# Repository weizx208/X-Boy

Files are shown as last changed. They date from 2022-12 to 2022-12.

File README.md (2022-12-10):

**基于全志V3s自制GBA开源游戏掌机**

视频介绍 [https://www.bilibili.com/video/BV1JP4y1X7Uz](https://www.bilibili.com/video/BV1JP4y1X7Uz/?vd_source=2f25de86752ccc9cfafc4bcf1c352db1)

图片展示

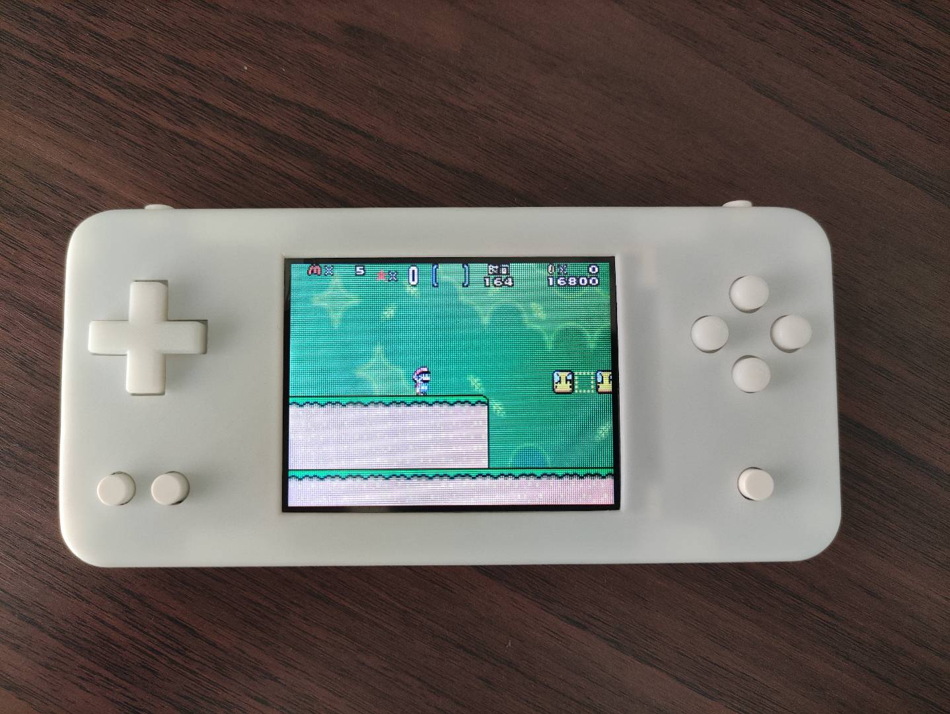
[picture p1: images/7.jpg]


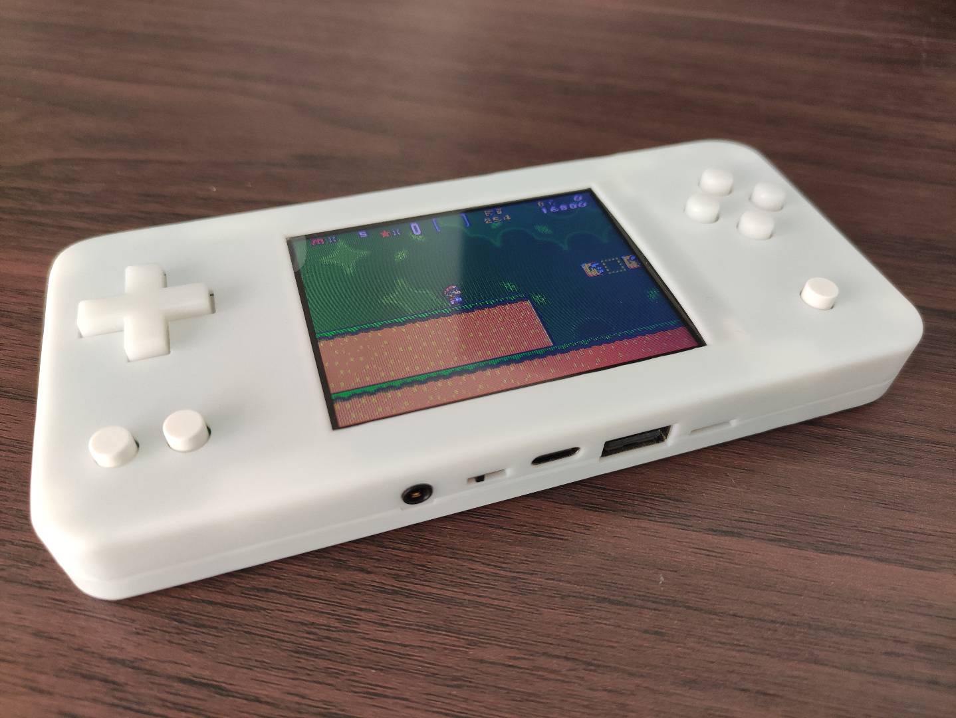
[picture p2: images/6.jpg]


以下内容为镜像的构建过程，你也可以直接使用我制作好的镜像

> 百度网盘
> 
> 链接：https://pan.baidu.com/s/1ftacGCXHLy-AFabczBg3yg
>
> 提取码：9bp8

**X-Boy 系统镜像构建全流程指南**

- [ubuntu 系统安装](#ubuntu-系统安装)
	- [下载镜像](#下载镜像)
	- [换源](#换源)
		- [备份源列表](#备份源列表)
		- [修改 sources.list 文件](#修改-sourceslist-文件)
		- [更改为清华镜像源](#更改为清华镜像源)
		- [更新并升级](#更新并升级)
		- [安装依赖库](#安装依赖库)
- [安装交叉编译工具链](#安装交叉编译工具链)
	- [安装编译器](#安装编译器)
		- [新建 tool 文件夹并进入](#新建-tool-文件夹并进入)
		- [下载交叉编译链](#下载交叉编译链)
		- [创建文件夹并解压](#创建文件夹并解压)
		- [配置环境变量](#配置环境变量)
		- [安装其他库](#安装其他库)
		- [验证是否安装成功](#验证是否安装成功)
- [uboot 编译](#uboot-编译)
	- [获取 uboot](#获取-uboot)
	- [修改 include/configs/sun8i.h](#修改-includeconfigssun8ih)
	- [编译 uboot](#编译-uboot)
- [主线 Linux 编译](#主线-linux-编译)
	- [下载源码](#下载源码)
	- [修改顶层 Makefile](#修改顶层-makefile)
	- [配置 ili9341 LCD](#配置-ili9341-lcd)
	- [编译](#编译)
- [Buildroot 根文件系统构建](#buildroot-根文件系统构建)
	- [获取 Buildroot](#获取-buildroot)
	- [基本配置](#基本配置)
	- [编译链工具配置](#编译链工具配置)
	- [alsa、sdl、fbv配置](#alsasdlfbv配置)
	- [编译](#编译-1)
- [TF 卡分区及烧录](#tf-卡分区及烧录)
	- [TF 卡分区](#tf-卡分区)
	- [烧录 uboot](#烧录-uboot)
	- [写入内核和设备树](#写入内核和设备树)
	- [写入根文件系统](#写入根文件系统)
- [编译模拟器](#编译模拟器)
	- [编译 gpsp](#编译-gpsp)
	- [复制可执行文件](#复制可执行文件)
- [系统配置](#系统配置)
	- [自动挂载 fat 分区](#自动挂载-fat-分区)
	- [配置双端显示](#配置双端显示)
	- [启动后开启声音](#启动后开启声音)
	- [配置 SDL 环境](#配置-sdl-环境)
	- [自启动模拟器](#自启动模拟器)
- [制作镜像](#制作镜像)
	- [创建工作目录](#创建工作目录)
	- [创建空白文件并分区](#创建空白文件并分区)
	- [将镜像文件虚拟成块设备](#将镜像文件虚拟成块设备)
	- [格式化块设备并且挂载](#格式化块设备并且挂载)
	- [烧录 uboot](#烧录-uboot-1)
	- [写入内核和设备树](#写入内核和设备树-1)
	- [写入根文件系统](#写入根文件系统-1)
- [感谢](#感谢)
- [参考链接](#参考链接)

---

## ubuntu 系统安装

### 下载镜像

```
https://mirrors.tuna.tsinghua.edu.cn/ubuntu-releases/18.04/ubuntu-18.04.6-desktop-amd64.iso
```

使用物理机或者虚拟机安装都可以

### 换源

#### 备份源列表

```
sudo cp /etc/apt/sources.list /etc/apt/sources.list.bak
```
#### 修改 sources.list 文件

```
sudo gedit /etc/apt/sources.list
```

#### 更改为清华镜像源

```
# 默认注释了源码镜像以提高 apt update 速度，如有需要可自行取消注释
deb https://mirrors.tuna.tsinghua.edu.cn/ubuntu/ bionic main restricted universe multiverse
# deb-src https://mirrors.tuna.tsinghua.edu.cn/ubuntu/ bionic main restricted universe multiverse
deb https://mirrors.tuna.tsinghua.edu.cn/ubuntu/ bionic-updates main restricted universe multiverse
# deb-src https://mirrors.tuna.tsinghua.edu.cn/ubuntu/ bionic-updates main restricted universe multiverse
deb https://mirrors.tuna.tsinghua.edu.cn/ubuntu/ bionic-backports main restricted universe multiverse
# deb-src https://mirrors.tuna.tsinghua.edu.cn/ubuntu/ bionic-backports main restricted universe multiverse
deb https://mirrors.tuna.tsinghua.edu.cn/ubuntu/ bionic-security main restricted universe multiverse
# deb-src https://mirrors.tuna.tsinghua.edu.cn/ubuntu/ bionic-security main restricted universe multiverse
# 预发布软件源，不建议启用
# deb https://mirrors.tuna.tsinghua.edu.cn/ubuntu/ bionic-proposed main restricted universe multiverse
# deb-src https://mirrors.tuna.tsinghua.edu.cn/ubuntu/ bionic-proposed main restricted universe multiverse
```

#### 更新并升级

```
sudo apt-get update && sudo apt-get upgrade
```

#### 安装依赖库

```
sudo apt-get install -y device-tree-compiler python flex bison ncurses-dev libssl-dev
```

## 安装交叉编译工具链

### 安装编译器

#### 新建 tool 文件夹并进入

```
mkdir ~/linux/tools && cd ~/linux/tools
```

#### 下载交叉编译链

```
wget https://releases.linaro.org/components/toolchain/binaries/4.9-2017.01/arm-linux-gnueabihf/gcc-linaro-4.9.4-2017.01-x86_64_arm-linux-gnueabihf.tar.xz
```

#### 创建文件夹并解压

```
sudo mkdir /usr/local/arm && sudo tar -vxf gcc-linaro-4.9.4-2017.01-x86_64_arm-linux-gnueabihf.tar.xz -C /usr/local/arm
```

#### 配置环境变量

```
sudo vim ~/.bashrc
export PATH=$PATH:/usr/local/arm/gcc-linaro-4.9.4-2017.01-x86_64_arm-linux-gnueabihf/bin
source ~/.bashrc
```
#### 安装其他库

```
sudo apt-get install lsb-core lib32stdc++6
```

#### 验证是否安装成功

```
arm-linux-gnueabihf-gcc -v
```

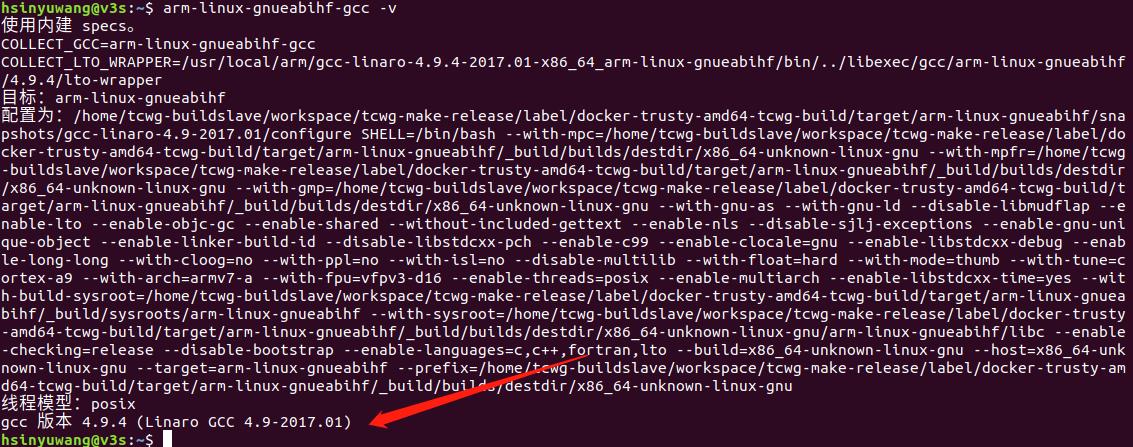
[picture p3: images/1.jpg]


## uboot 编译

### 获取 uboot

```
mkdir ~/v3s && cd ~/v3s
git clone https://github.com/Lichee-Pi/u-boot.git -b v3s-current
```
uboot 的目录结构

```
├── api                存放uboot提供的API接口函数
├── arch               平台相关的部分我们只需要关心这个目录下的ARM文件夹
│   ├──arm
│   │   └──cpu
│   │   │   └──armv7
│   │   └──dts
│   │   │   └──*.dts 存放设备的dts,也就是设备配置相关的引脚信息
├── board              对于不同的平台的开发板对应的代码
├── cmd                顾名思义，大部分的命令的实现都在这个文件夹下面。
├── common             公共的代码
├── configs            各个板子的对应的配置文件都在里面，我们的Lichee配置也在里面
├── disk               对磁盘的一些操作都在这个文件夹里面，例如分区等。
├── doc                参考文档，这里面有很多跟平台等相关的使用文档。
├── drivers            各式各样的驱动文件都在这里面
├── dts                一种树形结构（device tree）这个应该是uboot新的语法
├── examples           官方给出的一些样例程序
├── fs                 文件系统，uboot会用到的一些文件系统
├── include            头文件，所有的头文件都在这个文件夹下面
├── lib                一些常用的库文件在这个文件夹下面
├── Licenses           这个其实跟编译无关了，就是一些license的声明
├── net                网络相关的，需要用的小型网络协议栈
├── post              上电自检程序
├── scripts           编译脚本和Makefile文件
├── spl               second program loader，即相当于二级uboot启动。
├── test              小型的单元测试程序。
└── tools             里面有很多uboot常用的工具。
```
### 修改 include/configs/sun8i.h

在文件中添加

```
#define CONFIG_BOOTCOMMAND  "setenv bootm_boot_mode sec; " \
                            "load mmc 0:1 0x41000000 zImage; "  \
                            "load mmc 0:1 0x41800000 sun8i-v3s-licheepi-zero-dock.dtb; " \
                            "bootz 0x41000000 - 0x41800000;"

#define CONFIG_BOOTARGS "console=tty0 console=ttyS0,115200 panic=5 rootwait root=/dev/mmcblk0p2 earlyprintk rw  vt.global_cursor_default=0"
```

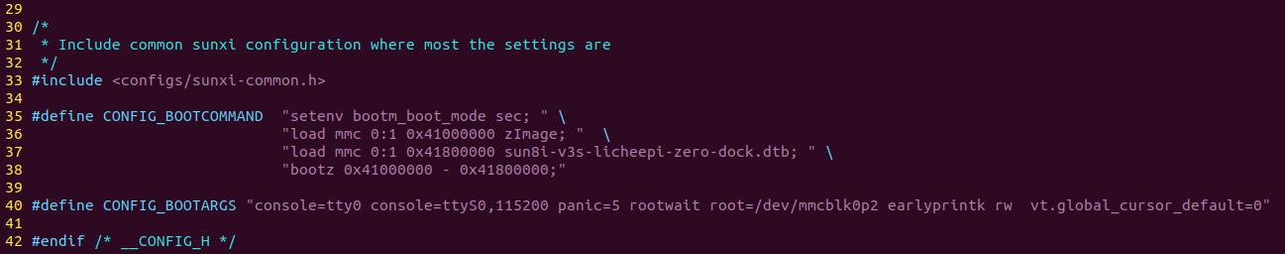
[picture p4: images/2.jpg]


### 编译 uboot

```
cd u-boot
make ARCH=arm CROSS_COMPILE=arm-linux-gnueabihf- LicheePi_Zero_defconfig
make ARCH=arm menuconfig
time make ARCH=arm CROSS_COMPILE=arm-linux-gnueabihf- 2>&1 | tee build.log
```

在 uboot 顶层 Makefile 的 248 行，添加默认编译器，就可以直接用 make 编译了。

```
# set default to nothing for native builds
ifeq ($(HOSTARCH),$(ARCH))
CROSS_COMPILE ?= 
endif

ARCH  ?= arm
CROSS_COMPILE ?= arm-linux-gnueabihf-

KCONFIG_CONFIG	?= .config
export KCONFIG_CONFIG
```

编译成功

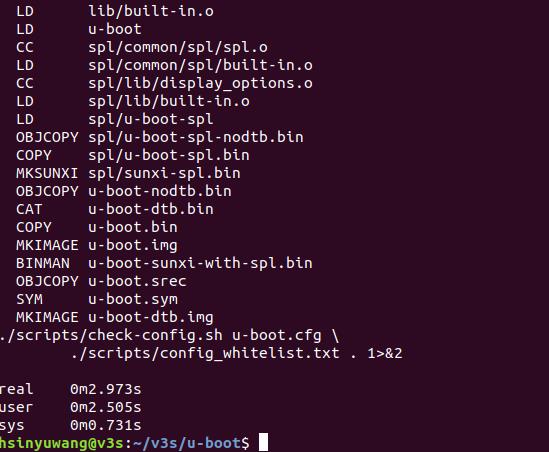
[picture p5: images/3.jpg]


后面编译好 kernel 和 rootfs 然后一起烧录

## 主线 Linux 编译

### 下载源码

```
cd ~/v3s
git clone -b zero-5.2.y https://github.com/Lichee-Pi/linux.git
```

### 修改顶层 Makefile

在内核根目录下的 Makefile 364 行修改默认编译器，可以直接用 make 编译

```
# ARCH		?= $(SUBARCH)
ARCH		?= arm
CROSS_COMPILE	?= arm-linux-gnueabihf-
```

### 配置 ili9341 LCD

```
cd linux
make licheepi_zero_defconfig
make menuconfig
```

勾选驱动

```
Device Drivers  --->
    Input device support  --->
        <*>   Joystick interface
        [*]   Joysticks/Gamepads  --->
             <*>   X-Box gamepad support
             [*]   X-Box gamepad rumble support
             [*]   LED Support for Xbox360 controller 'BigX' LED
    [ * ] Staging drivers  --->
        <*>   Support for small TFT LCD display modules  --->
                <*>   FB driver for the ILI9341 LCD Controller
                <*>   Generic FB driver for TFT LCD displays
```

修改设备树 arch/arm/boot/dts/sun8i-v3s-licheepi-zero.dts

在 chosen 中添加 /delete-node/ framebuffer@0; 删除原来的 simplefb 节点（ uboot 里有使能 fb 的操作，必须删除而不是 disable ）

```
chosen {
		stdout-path = "serial0:115200n8";
		/delete-node/ framebuffer@0;
	};
```

删除 &i2c0 节点

```
&i2c0 {
	status = "okay";

	ns2009: ns2009@48 {
		compatible = "nsiway,ns2009";
		reg = <0x48>;
	};
};
```

修改设备树 arch/arm/boot/dts/sun8i-v3s-licheepi-zero-dock.dts

删除 &lradc 和 &i2c0 （ lradc 用不到，gt911 占用引脚和屏幕的 spi 引脚有冲突，所以删掉）

```
&lradc {
	vref-supply = <&reg_vcc3v0>;
	status = "okay";

	button-200 {
		label = "Volume Up";
		linux,code = <KEY_VOLUMEUP>;
		channel = <0>;
		voltage = <200000>;
	};

	button-400 {
		label = "Volume Down";
		linux,code = <KEY_VOLUMEDOWN>;
		channel = <0>;
		voltage = <400000>;
	};

	button-600 {
		label = "Select";
		linux,code = <KEY_SELECT>;
		channel = <0>;
		voltage = <600000>;
	};

	button-800 {
		label = "Start";
		linux,code = <KEY_OK>;
		channel = <0>;
		voltage = <800000>;
	};
};

&i2c0 {
	gt911: touchscreen@14 {
        compatible = "goodix,gt911";
        reg = <0x5d>;
        interrupt-parent = <&pio>;
        interrupts = <1 5 IRQ_TYPE_EDGE_FALLING>; /* (PB5) */
        pinctrl-names = "default";
        irq-gpios = <&pio 1 5 GPIO_ACTIVE_HIGH>; /* (PB5) */
        reset-gpios = <&pio 2 1 GPIO_ACTIVE_HIGH>; /* RST (PC1) */
        /* touchscreen-swapped-x-y */
    };
};
```

在最后添加

```
&spi0 {
       status = "okay";

       ili9341@0 {
               compatible = "ilitek,ili9341";
               reg = <0>;

               spi-max-frequency = <60000000>;
               rotate = <270>;
               bgr;
               fps = <50>;
               buswidth = <8>;
               reset-gpios = <&pio 1 2 GPIO_ACTIVE_LOW>;
               dc-gpios = <&pio 1 5 GPIO_ACTIVE_LOW>;
               debug = <0>;
       };
};
```

这样启动时的信息会通过 ili9341 LCD 显示

5.2 内核需要修改 drivers/staging/fbtft/fbtft_core.c 的 fbtft_request_one_gpio() 方法，否则开机 log 会报申请 gpio 失败

注意需要在该文件引入下面头文件，否则编译报错

```
#include <linux/of_gpio.h>
```

```
static int fbtft_request_one_gpio(struct fbtft_par *par,
                  const char *name, int index,
                  struct gpio_desc **gpiop)
{
    struct device *dev = par->info->device;
    struct device_node *node = dev->of_node;
    int gpio, flags, ret = 0;
    enum of_gpio_flags of_flags;
    if (of_find_property(node, name, NULL)) {
        gpio = of_get_named_gpio_flags(node, name, index, &of_flags);
        if (gpio == -ENOENT)
            return 0;
        if (gpio == -EPROBE_DEFER)
            return gpio;
        if (gpio < 0) {
            dev_err(dev,
                "failed to get '%s' from DT\n", name);
            return gpio;
        }
         //active low translates to initially low
        flags = (of_flags & OF_GPIO_ACTIVE_LOW) ? GPIOF_OUT_INIT_LOW :
                            GPIOF_OUT_INIT_HIGH;
        ret = devm_gpio_request_one(dev, gpio, flags,
                        dev->driver->name);
        if (ret) {
            dev_err(dev,
                "gpio_request_one('%s'=%d) failed with %d\n",
                name, gpio, ret);
            return ret;
        }
 
        *gpiop = gpio_to_desc(gpio);
        fbtft_par_dbg(DEBUG_REQUEST_GPIOS, par, "%s: '%s' = GPIO%d\n",
                            __func__, name, gpio);
    }
 
    return ret;
}
```

修改引脚 bug

fbtft_bus.c 的 fbtft_write_vmem16_bus8() 方法

```
int fbtft_write_vmem16_bus8(struct fbtft_par *par, size_t offset, size_t len)
{
	u16 *vmem16;
	__be16 *txbuf16 = par->txbuf.buf;
	size_t remain;
	size_t to_copy;
	size_t tx_array_size;
	int i;
	int ret = 0;
	size_t startbyte_size = 0;
 
	fbtft_par_dbg(DEBUG_WRITE_VMEM, par, "%s(offset=%zu, len=%zu)\n",
		      __func__, offset, len);
 
	remain = len / 2;
	vmem16 = (u16 *)(par->info->screen_buffer + offset);
 
	if (par->gpio.dc)
	{
		//printk("dc拉高！\n");
		gpiod_set_value(par->gpio.dc, 1);
	}
	/* non buffered write */
	if (!par->txbuf.buf)
		return par->fbtftops.write(par, vmem16, len);
 
	/* buffered write */
	tx_array_size = par->txbuf.len / 2;
 
	if (par->startbyte) {
		txbuf16 = par->txbuf.buf + 1;
		tx_array_size -= 2;
		*(u8 *)(par->txbuf.buf) = par->startbyte | 0x2;
		startbyte_size = 1;
	}
 
	while (remain) {
		to_copy = min(tx_array_size, remain);
		dev_dbg(par->info->device, "to_copy=%zu, remain=%zu\n",
			to_copy, remain - to_copy);
 
		for (i = 0; i < to_copy; i++)
			txbuf16[i] = cpu_to_be16(vmem16[i]);
 
		vmem16 = vmem16 + to_copy;
		ret = par->fbtftops.write(par, par->txbuf.buf,
						startbyte_size + to_copy * 2);
		if (ret < 0)
			return ret;
		remain -= to_copy;
	}
 
	return ret;
}
```

### 编译

```
make -j4
make -j4 INSTALL_MOD_PATH=out modules
make -j4 INSTALL_MOD_PATH=out modules_install
# 修改了设备树文件后编译
make dtbs
```

- 编译完成后，zImage 在 arch/arm/boot/ ，驱动模块在 out/
- 设备树文件在 arch/arm/boot/dts/
- dock板的设备树：sun8i-v3s-licheepi-zero-dock.dtb

## Buildroot 根文件系统构建

### 获取 Buildroot

```
cd ~/v3s
wget https://buildroot.org/downloads/buildroot-2019.08.tar.gz
tar xvf buildroot-2019.08.tar.gz && cd buildroot-2019.08/
make menuconfig
```

### 基本配置

```
Target options  --->
	Target Architecture (ARM (little endian))  --->
	Target Binary Format (ELF)  --->
	Target Architecture Variant (cortex-A7)  --->
	Target ABI (EABIhf)  --->
	Floating point strategy (VFPv4-D16)  --->
	ARM instruction set (ARM)  ---> 
```

### 编译链工具配置

```
Toolchain  --->
	Toolchain type (External toolchain)  --->
	*** Toolchain External Options ***
	Toolchain (Custom toolchain)  --->
	Toolchain origin (Pre-installed toolchain)  --->
	(/usr/local/arm/gcc-linaro-4.9.4-2017.01-x86_64_arm-linux-gnueabihf/) Toolchain path
	($(ARCH)-linux-gnueabihf) Toolchain prefix
	External toolchain gcc version (4.9.x)  --->
	External toolchain kernel headers series (4.0.x)  --->
	External toolchain C library (glibc/eglibc)  --->
	[*] Toolchain has SSP support? (NEW)
	[*] Toolchain has RPC support? (NEW)
	[*] Toolchain has C++ support? 
	[*] Enable MMU support (NEW) 
```

### alsa、sdl、fbv配置

```
Target packages  --->
	Audio and video applications  --->
		[*] alsa-utils  --->
		[*]   alsaconf
		[*]   aconnect
		[*]   alsactl
		[*]   alsaloop
		[*]   alsamixer
		[*]   alsaucm
		[*]   alsatplg
		[*]   amidi
		[*]   amixer
		[*]   aplay/arecord
		[*]   aplaymidi
		[*]   arecordmidi
		[*]   aseqdump
		[*]   aseqnet
		[*]   bat
		[*]   iecset
		[*]   speaker-test
	Graphic libraries and applications (graphic/text)  --->
		[*] fbv
		[*]   PNG support
		[*]   JPEG support
		[*]   GIF support 
		[*] SDL
		[*]   SDL framebuffer console video driver
		[*]   SDL_gfx
		[*]   SDL_image  --->
		[*]   SDL_mixer
		[*]   SDL_net
		[*]   SDL_sound
		[*]     install playsound tool
		[*]   SDL_TTF
```
### 编译

```
make -j4
```

生成的根文件系统在 output/images/rootfs.tar

## TF 卡分区及烧录

### TF 卡分区

```
sudo fdisk -l     		# 首先查看电脑上已插入的TF卡的设备号（一般为 /dev/sdb1,下面以/dev/sdb1为例）
sudo umount /dev/sdb1 	# 若自动挂载了TF设备，请先卸载(有多个分区则全部卸载)
sudo umount /dev/sdb2
sudo fdisk /dev/sdb   	# 进行分区操作
##### 操作步骤如下 #####
# 若已存分区即按 d 删除各个分区
# 通过 n 新建分区，第一分区暂且申请为16M(f1c100s)、32M(v3s)，剩下的空间都给第二分区
	# 第一分区操作：n p 1 2048 +32M
		# p 主分区、默认 1 分区、默认2048、+32M
	# 第二分区操作：n 后面全部回车默认即可
		# p 主分区、默认 2 分区、默认、默认剩下的全部空间
# p 查询分区表确定是否分区成功
# w 保存写入并退出
########################

sudo mkfs.ext4 /dev/sdb1 # 将第一分区格式化成EXT4
sudo mkfs.ext4 /dev/sdb2 # 将第二分区格式化成EXT4

# 格式说明
	# EXT4：只用于Linux系统的内部磁盘
	# NTFS：与Windows共用的磁盘
	# FAT：所有系统和设备共用的磁盘
```

后期为了能够在 windows 上方便添加 rom ，使用 gparted 划分三个分区，最后一个分区为 fat 类型

安装并启动

```
sudo apt-get install gparted
sudo gparted
```

分区如下

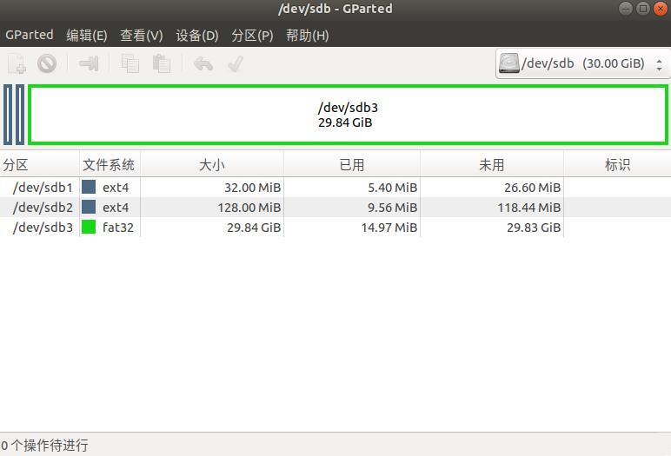
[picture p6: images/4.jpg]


### 烧录 uboot

```
cd ~/v3s/u-boot/
sudo dd if=u-boot-sunxi-with-spl.bin of=/dev/sdb bs=1024 seek=8
```
### 写入内核和设备树

```
sudo cp ~/v3s/linux/arch/arm/boot/zImage /挂载的tf卡第一个分区目录
sudo cp ~/v3s/linux/arch/arm/boot/dts/sun8i-v3s-licheepi-zero-dock.dtb /挂载 tf 卡第一个分区目录
```

### 写入根文件系统

```
sudo tar xvf ~/v3s/buildroot-2019.08/output/images/rootfs.tar -C /挂载 tf 卡第二个分区目录
```

## 编译模拟器

### 编译 gpsp

```
cd ~/v3s
git clone https://github.com/hsinyuwang/gpsp.git

cd gpsp/v3s
make -j4
```
### 复制可执行文件

将生成的可执行文件复制到挂载的 tf 卡第二个分区目录，gpsp 同级目录下必须包含 gba_bios.bin 和 game_config.txt 文件

例如：
- 在 /root 下创建 gpsp 文件夹，将 gpsp、gba_bios.bin、game_config.txt 复制到 gpsp 文件夹中
- 在 /root 下创建 fceux 文件夹，将 fceux 复制到 fceux 文件夹中

## 系统配置

插入 TF 卡，开机

### 自动挂载 fat 分区

```
mkdir /root/roms
vi /etc/fstab

# 最后一行添加
/dev/mmcblk0p3  /root/roms      vfat    defaults        0       0
```

### 配置双端显示

```
vi /etc/inittab

#console::respawn:-/bin/sh
ttyS0::respawn:-/bin/sh
tty0::respawn:-/bin/sh
```

### 启动后开启声音

```
vi /etc/init.d/S99runOnBoot

# 添加
amixer -c 0 sset 'Headphone',0 60% unmute

# 添加可执行权限
chmod +x /etc/init.d/S99runOnBoot
```

### 配置 SDL 环境

```
vi /etc/profile

# SDL 配置
export SDL_NOMOUSE=1

# 启动模拟器
/root/startup.sh
```

### 自启动模拟器

```
vi /root/startup.sh

#!/bin/sh /root/startup.sh
for i in `seq 5`
do
        sleep 1s
        if [ -c "/dev/input/js0" ]
        then
                /root/gpsp/gpsp
                break
        else
                if [ $i -eq 5 ]
                then
                        echo "No gamepad found!"
                fi
        fi
done

chmod +x startup.sh
```

## 制作镜像

### 创建工作目录

```
mkdir ~/img
cd ~/img
mkdir kernel
mkdir rootfs
mkdir roms
```

### 创建空白文件并分区

分区表

| 分区序号 | 起始地址 | 大小 | 内容 | 文件系统 |
| ---- | ---- | ---- | ---- | ---- |
| 1 | 0 | 1M | u-boot-sunxi-with-spl.bin | 无 |
| 2 | 1 x 1024 x 1024 | 32M | zImage + sun8i-v3s-licheepi-zero-dock.dtb | ext4 |
| 3 | 33 x 1024 x 1024 | 128M | rootfs | ext4 |
| 4 | 161 x 1024 x 1024 | 剩余空间 | roms | fat |

```
dd if=/dev/zero of=X-Boy_20221019.img bs=512k count=512  && sync
sudo parted X-Boy_20221019.img mklabel msdos
sudo parted X-Boy_20221019.img mkpart primary ext4 2048s 67583s
sudo parted X-Boy_20221019.img mkpart primary ext4 67584s 329727s
sudo parted X-Boy_20221019.img mkpart primary fat32 329728s 100%
```

检查分区是否创建成功

```
sudo parted X-Boy_20221019.img
```

输入

```
print free

# 退出
q
```

### 将镜像文件虚拟成块设备

```
sudo losetup -f --show X-Boy_20221019.img
```

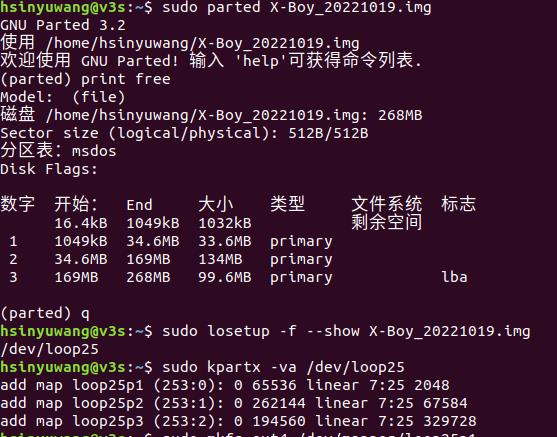
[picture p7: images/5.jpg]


这里的 loop25 记录下来 ，以实际显示为准

挂载虚拟文件系统

```
sudo kpartx -va /dev/loop25
```

### 格式化块设备并且挂载

格式化分区

```
sudo mkfs.ext4 /dev/mapper/loop25p1
sudo mkfs.ext4 /dev/mapper/loop25p2
sudo mkfs.vfat /dev/mapper/loop25p3
```

挂载到之前创建的目录

```
sudo mount /dev/mapper/loop25p1 ~/img/kernel/
sudo mount /dev/mapper/loop25p2 ~/img/rootfs/
sudo mount /dev/mapper/loop25p3 ~/img/roms/
```

### 烧录 uboot

```
cd ~/v3s/u-boot/
sudo dd if=u-boot-sunxi-with-spl.bin of=/dev/loop25 bs=512 seek=16
```

### 写入内核和设备树

```
sudo cp ~/v3s/linux/arch/arm/boot/zImage ~/img/kernel
sudo cp ~/v3s/linux/arch/arm/boot/dts/sun8i-v3s-licheepi-zero-dock.dtb ~/img/kernel
```

### 写入根文件系统

```
sudo tar xvf ~/v3s/buildroot-2019.08/output/images/rootfs.tar -C ~/img/rootfs
```

## 感谢

[steward-fu](https://github.com/steward-fu)

[STM32-X360-xinput](https://github.com/nesvera/STM32-X360-xinput)

## 参考链接

[全志V3S（荔枝派zero）学习笔记](https://blog.csdn.net/p1279030826/article/details/114981681)

[荔枝派Zero V3s开发板入坑记录](https://whycan.com/t_561.html)

[Linux系统中使用Xbox360手柄](http://t.zoukankan.com/beyonne-p-10932152.html)

[f1c100s spi fbtft ILI9341屏配置](https://blog.csdn.net/qulang000/article/details/114686525)

[点屏之SPI屏 ili9341](https://www.kancloud.cn/lichee/lpi0/538999)

[嵌入式Linux--荔枝派Zero--V3s--ST7789v](https://blog.csdn.net/qq_28877125/article/details/120007416)

[v3S驱动音频](https://blog.csdn.net/lengyuefeng212/article/details/120055703)

[制作imx6ull Linux系统的img镜像](https://blog.csdn.net/mzy2364/article/details/113364250)

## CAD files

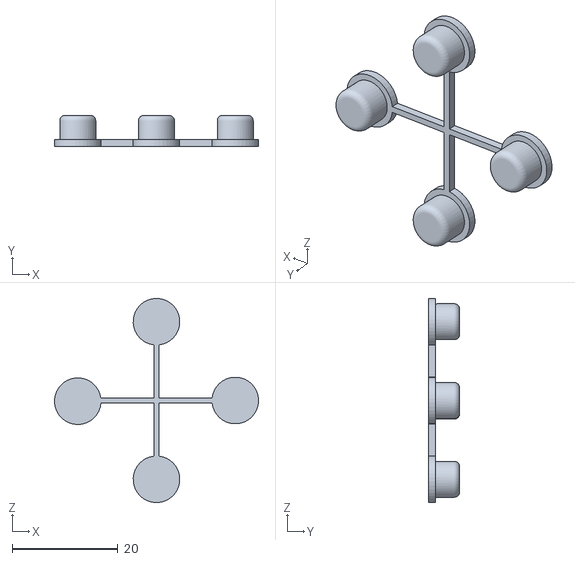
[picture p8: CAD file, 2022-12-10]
STL/ABXY.STL
38.5 x 5.90 x 38.5

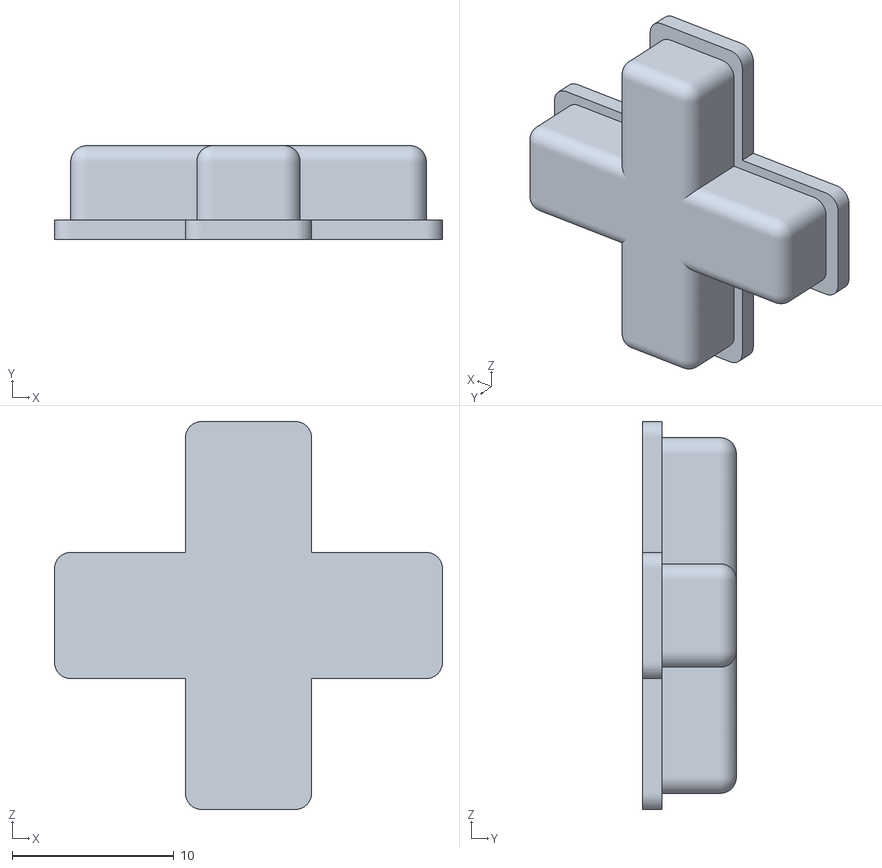
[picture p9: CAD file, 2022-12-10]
STL/十字键.STL
24.0 x 5.80 x 24.0

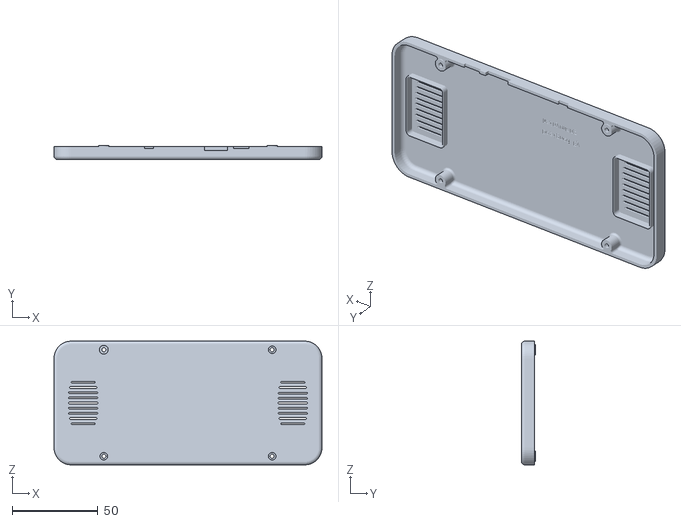
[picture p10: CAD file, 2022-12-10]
STL/下壳.STL
156.0 x 8.20 x 72.0

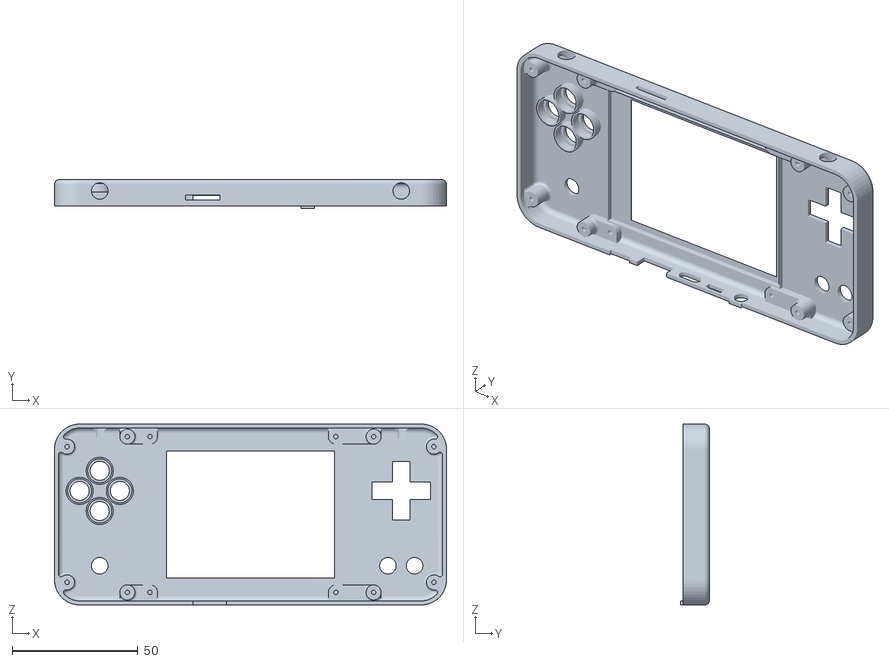
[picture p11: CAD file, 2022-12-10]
STL/上壳.STL
156.0 x 11.6 x 72.0

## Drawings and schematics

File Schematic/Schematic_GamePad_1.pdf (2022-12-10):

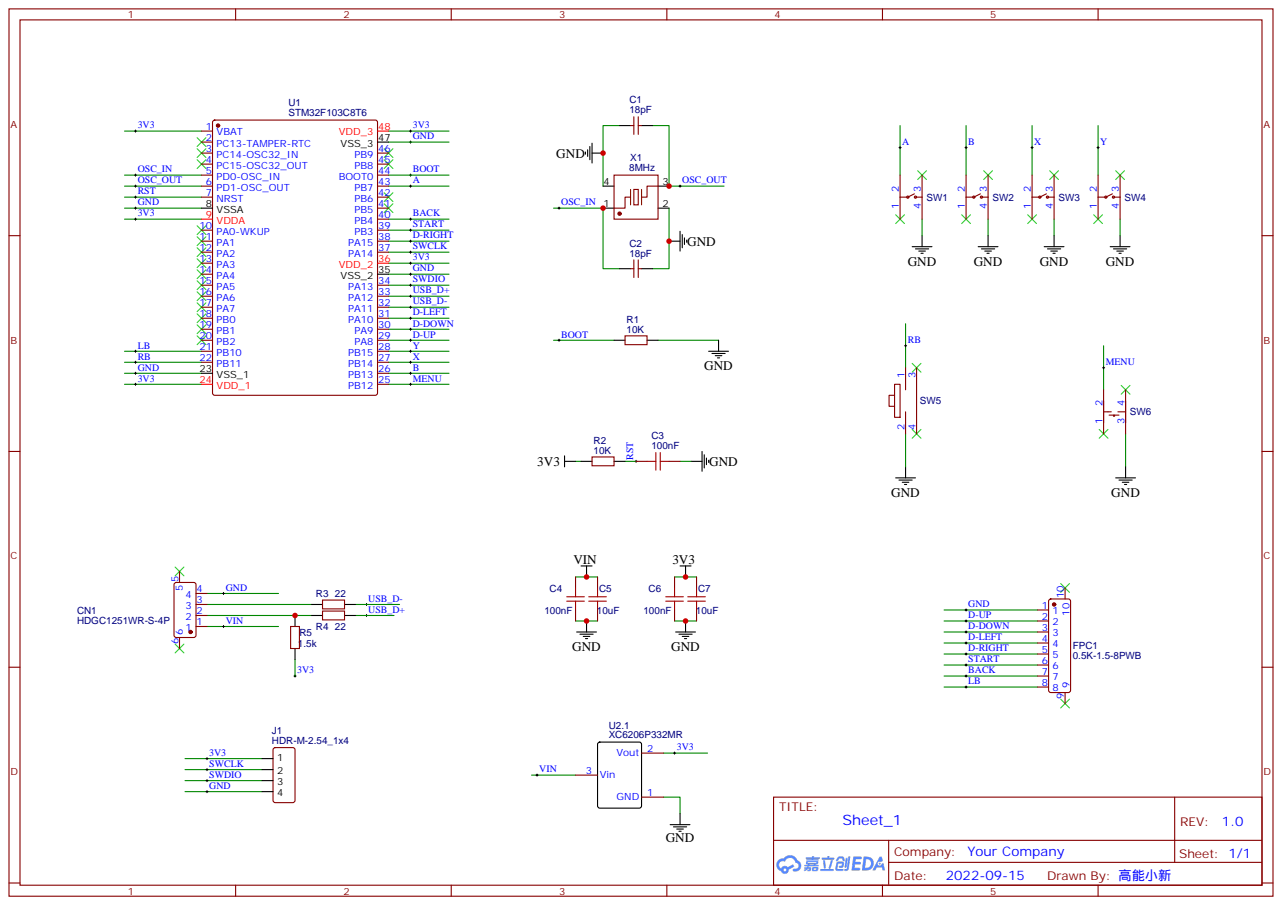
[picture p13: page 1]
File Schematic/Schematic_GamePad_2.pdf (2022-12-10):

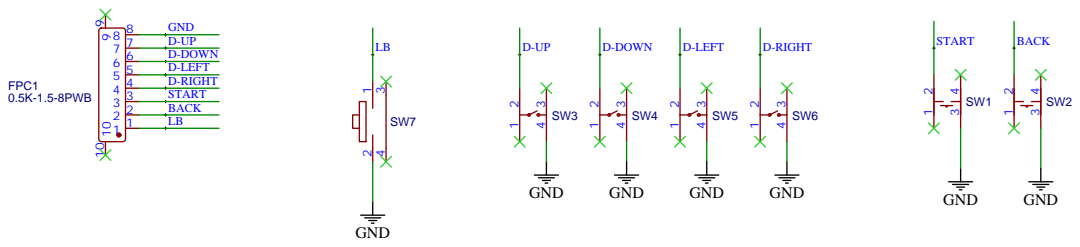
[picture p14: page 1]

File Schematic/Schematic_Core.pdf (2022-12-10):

# TF_CARD

# CORE

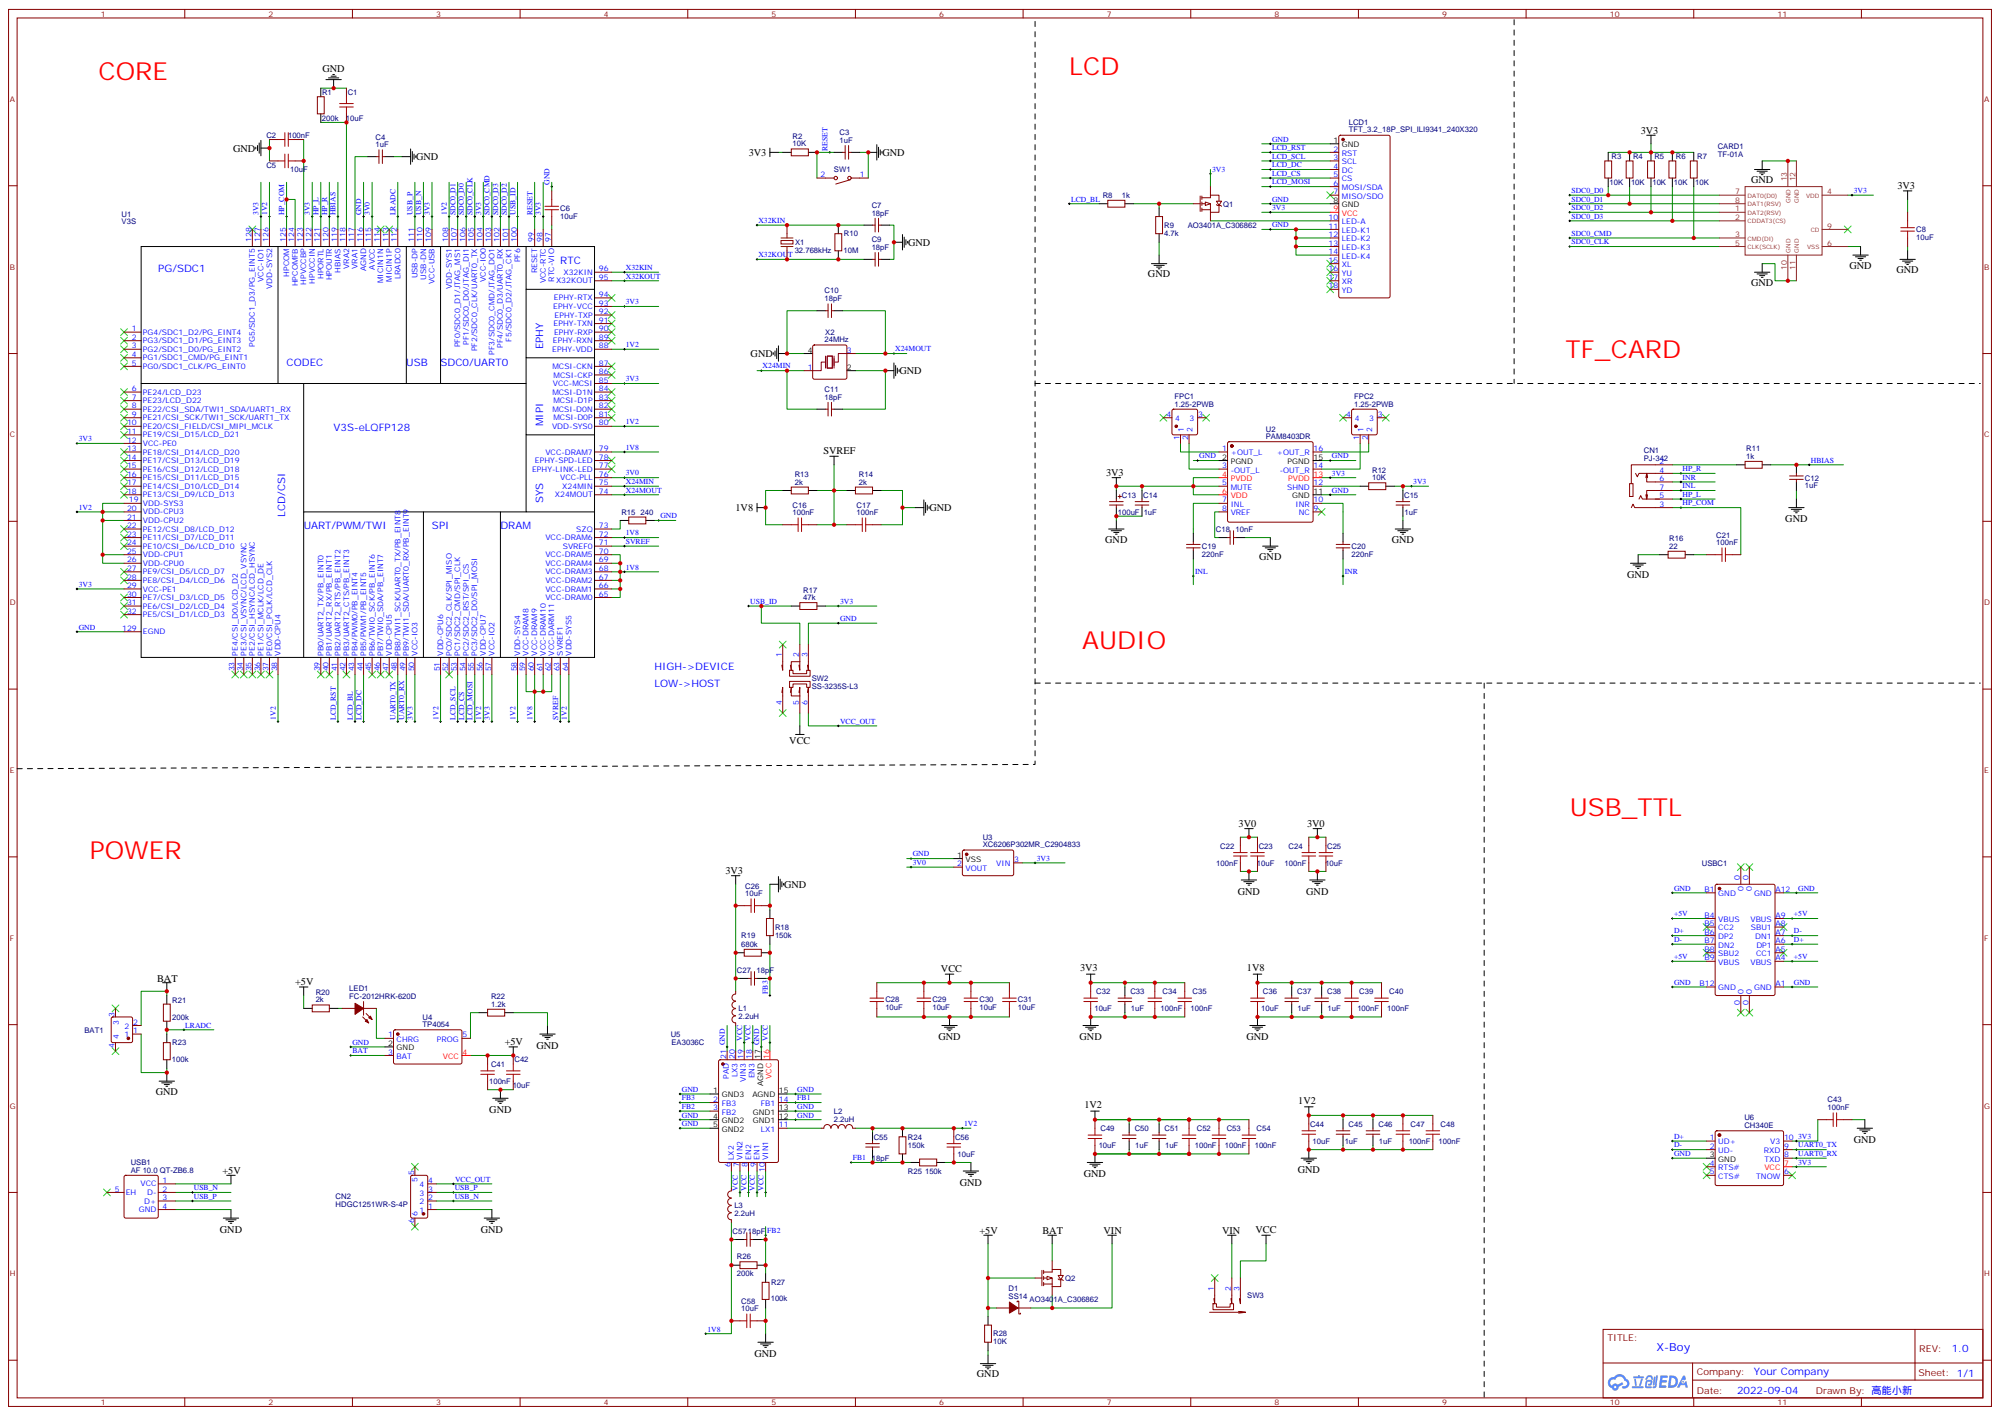
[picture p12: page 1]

VCC-DRAM0 65 VDD⁻SYS5 64 SVREF1 63 VCC⁻DARM¹¹ 62 VCC⁻DRAM¹⁰ 61 VCC⁻DRAM⁹ 60 VCC⁻DRAM⁸ 59 VDD⁻SYS4 58

LX1 11 GND1 12 GND1 13 FB1 14 AGND 15 VCC 16 AGND ¹⁷ EN³ ¹⁸
